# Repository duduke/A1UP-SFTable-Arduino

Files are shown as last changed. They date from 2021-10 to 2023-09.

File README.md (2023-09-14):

--one more test
--This is Just a Test
--One more test

## Street Fighter Arcade1Up Table Arduino Interface
### Goal of this project
Arcade1Up uses proprietary circuit boards to interface with the game's circuit board through a 12 pin IDC cable. The goal of this project is to create an interface for any PC that can be hooked directly to their proprietary circuit board via the IDC cable and interpret the output as a couple of joysticks.

I chose the Arduino Leonardo for it's ability to emulate USB devices and the ease of creating shields with it's form factor. 

### IDC 12 Pinout
| Pin | Function |
|--|--|
| 1 | Speaker(UNUSED) |
| 2 | Speaker(UNUSED) |
| 3 | GND |
| 4 | GND |
| 5 | UART(3.3V) 1 TX |
| 6 | UART(3.3V) 1 RX |
| 7 | 5V |
| 8 | GND |
| 9 | UART(3.3V) 2 RX |
| 10 | UART(3.3V) 2 TX |
| 11 | Power Switch |
| 12 |Gnd |

While there is a place for a speaker connection on the circuit board, it is not connected to anything as the speakers on the cabinets of this style are connected directly to their game board. There are two uart connections that send all controller data, however this model only uses the first.

The unit uses a latching switch for it's powerbutton, however I changed mine out for a momentary switch because I altered mine to replace a laptop board's power switch.

### UART encoding
I used a logic analyzer to decode what was going on via the serial communication. Looking at the rate of pulses I found out it was 115200 speed. Counting the pulses based on that speed I found out it was 8n1.

The game board polls the controller board every 20 ms by sending 3 bytes:

    A6 01 00
The board then responds by sending something like this:

    A7 10 0V 01 SJ XY 00 02 SJ XY 00 00 00 00 00 00 00 00

 - A710 is just the Header.
 - 01 is the header for player one
 - V(4 bits) is the volume switch placement. 0 is towards the left, 1 is centered, and 2 is to the right
 - S(4 bits) is the start button. 0010 is pressed, 0 is not
 - J(4 bits) is the joystick. 0001 is Down, 0010 is Left, 0100 is Up, and 1000 is Right. You can OR them for combinations.
 - X(4 bits) is for two buttons. 0001 is Jab and 0010 is Roundhouse. You can OR them for both being pressed
 - Y(4 bits) is for the four other buttons. 0001 is Forward, 0010 is Strong, 0100 is Fierce, and 1000 is Short.
 - 02 is the header for player 2. The rest are the same for as player 1.

On the four player cabinets, the second UART is the same format and still uses 01 and 02 to signify players 3 and 4, while Volume is always set to 2 on the second UART. It's not used for this project, but is pretty cool none the less.

### Putting it together
Knowing how the UART works and what pins go where, I prototyped my device. Due to the Leonardo using 5V logic and the controller board using 3.3V I had to reduce the voltage of my output to it, incase 5V might damage it. The Leonardo should read 3.3V just fine as it's within it's threshold. I first tried a simple voltage divider circuit, but it did not work. I suspect it pulled the power down too much and the controller board failed to read it. 

The solution, integrate a level shifter. Thankfully there are already boards that do that which are faily cheap, so I ordered some sparkfun ones, et voila, it worked! 

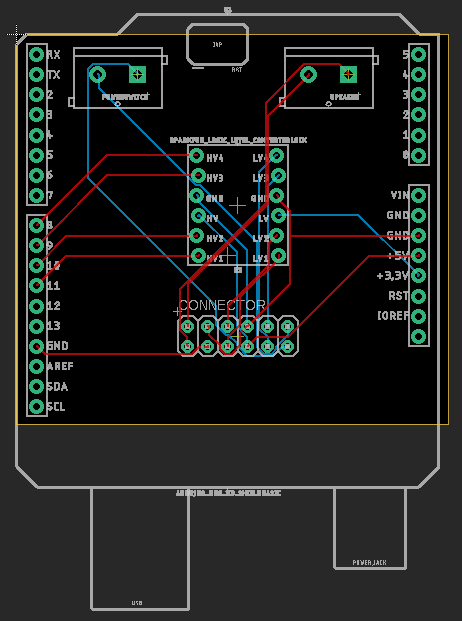
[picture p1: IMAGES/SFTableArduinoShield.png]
View of Circuit Board Design


Since I got the circuit working and programmed a solution, all I needed to do was fabricate a board and solder it. One last thing I needed to do was write a shader to split the screen, so that both sides of the table can see the same view. I hadn't done shader coding before, but it was a quick enough learn to do. I decided to use reShade to inject the shader as it becomes automatic after setup.

You'll find the fabrication files and the source code to this in this repository.

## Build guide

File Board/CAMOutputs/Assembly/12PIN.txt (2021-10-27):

Partlist exported from C:/Users/Quasari/Documents/EAGLE/projects/A1Up20pin/12PIN.sch at 9/26/2020 9:44 PM

Qty Value                              Device                             Package                             Parts                Description                                                                                                     POPULARITY SF_SKU   
2                                      CONN_025MM                         SCREWTERMINAL-5MM-2                 POWERSWITCH, SPEAKER Multi connection point. Often used as Generic Header-pin footprint for 0.1 inch spaced/style header connections            PRT-08432
1                                      PINHD-2X6                          2X06                                CONNECTOR            PIN HEADER                                                                                                      8                   
1   ARDUINO_UNO_R3_SHIELDBASIC         ARDUINO_UNO_R3_SHIELDBASIC         UNO_R3_SHIELD                       B1                   Arduino R3 Shield Footprint                                                                                                         
1   SPARKFUN_LOGIC_LEVEL_CONVERTERLOCK SPARKFUN_LOGIC_LEVEL_CONVERTERLOCK SPARKFUN_LOGIC_LEVEL_CONVERTER_LOCK B2                   SparkFun Logic Level Converter -Bi-Directional

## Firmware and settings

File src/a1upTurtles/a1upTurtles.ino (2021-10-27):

/*
  Used to interface with turtles control panel
*/
#define HID_CUSTOM_LAYOUT
#define LAYOUT_US_ENGLISH


#include <SoftwareSerial.h>
#include <HID-Project.h>

// We have two ports used by the turtles board, One for one/two, Two for three/four
SoftwareSerial portTwo(8, 9);
SoftwareSerial portOne(10, 11);

const byte volumeUp = B00000010;

const byte sendSignal[3] = {0xA6, 0x01, 0x00};

const KeyboardKeycode keyCodes[4][8] = {{KEY_D, KEY_S, KEY_A, KEY_W, KEY_3, KEY_Z, KEY_2, KEY_1},
                                {KEY_H, KEY_G, KEY_F, KEY_T, KEY_6, KEY_V, KEY_5, KEY_4},
                                {KEY_L, KEY_K, KEY_J, KEY_I, KEY_9, KEY_M, KEY_8, KEY_7},
                                {KEY_RIGHT,KEY_DOWN,KEY_LEFT,KEY_UP, KEY_EQUAL, KEY_COMMA, KEY_MINUS, KEY_0}};

//                             right  down   left   up     turbo  start  jump   attack vDown  vUp
boolean controllers[4][10];

// I don't know if it's my logic level voltage shifter introducing lag or just a problem with the cab, but we get phantom output every
// once in a while. My solution is to poll twice as fast and only take a press if it's pressed for 2 polls. Same thing for a release.
byte fixers[4][10];

// timers used for debouncing and volume limiters
long timers[4][10];

const ConsumerKeycode cons[] = {MEDIA_VOLUME_DOWN, MEDIA_VOLUME_UP};

// used when holding 1p start to exit game
unsigned long exit_time = 0;
bool check_exit = false;

void setup() 
{
  pinMode(8, INPUT);
  pinMode(9, OUTPUT);
  pinMode(10, INPUT);
  pinMode(11, OUTPUT);

  //Both ports are 115200
  portOne.begin(115200);
  portTwo.begin(115200);
  Keyboard.begin();
  Consumer.begin();
}

// Checks button j input on controller i using bounce protection. 
bool checkButtonInput(int i,int j) 
{
  switch(fixers[i][j]) 
  {
  case 0: // Unpressed
    if (controllers[i][j]) fixers[i][j]++;
    break;
  case 1:  // pressed for one polls
    if (controllers[i][j]) 
    {
      fixers[i][j]++;
      timers[i][j] = millis();
      return true;
    }
    fixers[i][j]--;
    break;
  case 2: // pressed for two or more polls
    if (millis() < timers[i][j]) timers[i][j] = 0;
    if (!controllers[i][j]) fixers[i][j]++;
    return true;
  case 3: // unpressed for one polls
    if (controllers[i][j] || millis() - timers[i][j] < 5)
    {
      fixers[i][j]--;
      return true;
    } 
    fixers[i][j] = 0;
    break;
  default:
    break;
  }
  return false;
}

void clearControls() 
{
  for(int i = 0; i < 4; i++) {
    for (int j = 0; j < 10; j++) {
      controllers[i][j] = false;
    }
  }
}

// polls the controller and reads data
void readControls(int set) 
{
  SoftwareSerial *port;
  switch(set) 
  {
    case 0:
      port = &portOne;
      break;
    case 1:
      port = &portTwo;
      break;
    default:
      return;
  }
  byte loopCount = 0;
  byte buffer[18];
  port->listen();
  port->write(sendSignal, 3);
  delayMicroseconds(1563); // time it takes to send 18 bytes 8n1 on 115200
  while(port->available() > 0) 
  {
    buffer[loopCount] = port->read();
    loopCount++;
  }
  if (loopCount == 18 && buffer[0] == 0xA7 && buffer[1] == 0x10 && buffer[3] == 0x01 && buffer[7] == 0x02) 
  {
    // we are in business, everything sent, everything is in correct spot
    if (buffer[2] == volumeUp) controllers[set*2][9] = true;
    else if (buffer[2] == 0)  controllers[set*2][8] = true;
    for(int j = 0; j <2; j++) 
    {
      for(int i = 0; i < 6; i++) 
      {
        if (i == 4) continue;
        controllers[set*2+j][i] = (buffer[4+j*4] & (1 << i)) > 0;
      }
      
      for(int i = 0; i < 4; i++) 
      {
        if (i == 1) continue;
        controllers[set*2+j][4+i] = (buffer[5+j*4] & (B00000010 << i)) > 0;
      }
    }
  }
}

// checks if a button is pressed and presses/releases it based on state
void writeButton(int i, int j) 
{
  int oldState = fixers[i][j];
  if (checkButtonInput(i,j)) 
  {
    if (oldState == 1) Keyboard.press(keyCodes[i][j]);
    return;
  }
  if (oldState == 3) Keyboard.release(keyCodes[i][j]);
}

// iterates over buttons on controller and writes value
void buttonsWriter(int i)
{
  for(int j = 0; j < 8; j++) 
  {
    writeButton(i,j);
  }
}

// checks if the switch is in a position and timing to change volume
void writeVolume(int i) 
{
  if (!controllers[0][8+i] && fixers[0][8+i] < 2)
  {
    fixers[0][8+i] = 0;
    return;
  }
    
  switch(fixers[0][8+i]) 
  {
  case 0: // Unpressed
    fixers[0][8+i]++;
    break;
  case 1:
    fixers[0][8+i]++;
    break;
  case 2:
    timers[0][8+i] = millis();
    fixers[0][8+i]++;
    Consumer.write(cons[i]);
    break;
  case 3: // pressed for 1/60th and above.
    if (millis() < timers[0][8+i]) timers[0][8+i] = 0;
    if (millis() - timers[0][8+i] >= 250) fixers[0][8+i] = 0;
    break;
  default:
    break;
  }
}

// iterates over the two volume switches and deals with them
void volumeWriter() 
{
  for (int i = 0; i < 2; i++)
  {
    writeVolume(i);
  }
}

void loop() 
{
  clearControls();
  readControls(0); // p1 and 2
  readControls(1); // p3 and 4
  
  for(int i = 0; i < 4; i++) 
  {
    buttonsWriter(i);
  }
    
  // volume checks
  volumeWriter();
  
  if (fixers[0][5] > 1) 
  {
    if (!check_exit) 
    {
      check_exit = true;
      exit_time = millis();
    }
    if (millis() < exit_time) exit_time = 0;
    if ((millis()-exit_time >= 5000)) Keyboard.write(KEY_ESC);
    
    return;
  }
  check_exit = false;
}

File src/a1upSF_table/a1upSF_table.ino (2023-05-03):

/*
    Street Fighter Table a1up
*/

#include <SoftwareSerial.h>
#include <Joystick.h>
#include <HID-Project.h>

Joystick_ Joystick[2] = 
{ Joystick_(0x20, JOYSTICK_TYPE_GAMEPAD, 7, 1, 0,0,0,0,0,0,0,0,0,0,0),
  Joystick_(0x30, JOYSTICK_TYPE_GAMEPAD, 7, 1, 0,0,0,0,0,0,0,0,0,0,0)};

SoftwareSerial portOne(10,11);

const byte volumeUp = B00000010;

const byte sendSignal[3] = {0xA6, 0x01, 0x00};

//                             Down   Left   Up     Right  VUP    Start  Frwrd  Strong Fierce Short  Jab    RndHose Vdown
byte fixers[2][13];

int timers[2][13];

unsigned long exit_time = 0;
bool check_exit = false;

void setup() {
    pinMode(10,INPUT);
    pinMode(11,OUTPUT);
    
    portOne.begin(115200);
    
    Joystick[0].begin();
    Joystick[1].begin();
    
    Keyboard.begin();
}

void readyExit()
{
  check_exit = true;
  exit_time = millis();
}

boolean controllers[2][13];

void loop() {
  // clear controller inputs from last loop.
  memset(controllers[0],0,sizeof(controllers[0]));
  memset(controllers[1],0,sizeof(controllers[1]));
  
  readInput();
  
  writeJoysticks();
  
  writeVolumeSwitch();
  // check if p1 start is being pressed for 5secs or more, and send a keyboard ESC signal
  if (fixers[0][5] > 1) {
    if (!check_exit) readyExit();
    
    if (millis() < exit_time) exit_time = 0;
    
    if ((millis()-exit_time >= 5000)) Keyboard.write(KEY_ESC);
    return;
  } 
  
  check_exit = false;
}

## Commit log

2021-10-27 Create a1upSF_table.ino
    Source code for Arduino.
2023-05-03 Changed volume button handling to send keyboard volume up and down
